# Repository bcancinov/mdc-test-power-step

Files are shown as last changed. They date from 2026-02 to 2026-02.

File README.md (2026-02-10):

# mdc-test-power-step
Modular Detector Controller Test Power Step Board

## Overview
This board generates controlled load steps at multiple bias rails to evaluate DC/DC module stability, settling, and control-loop bandwidth under different load conditions. It is intended to be used alongside the `mdc-power-*` DC/DC module boards.

## Objective
- Test stability and transient response across different bias rails.
- Measure settling time and bandwidth under programmable load conditions.

## System Context
- DC/DC generation is provided by the `mdc-power-*` boards.
- This board provides load-step capability and measurement access for those rails.
- Board input: 12V.

## Board Stackup
- 4-layer PCB

## Board Dimensions
- 136.4 mm x 105.35 mm

## CAD
- Designed using KiCad 9.

## Key Functions
- Programmable load steps using MOSFET-switched resistor banks.
- Multiple selectable load levels per rail.
- Local support rails and timing (LDO + oscillator) for step control.
- External 3.3V step input for injecting step signals on both positive and negative DUT outputs.
- 2 MHz oscillator to provide a sync reference for the DC-DC DUT.

## Images
Layout:
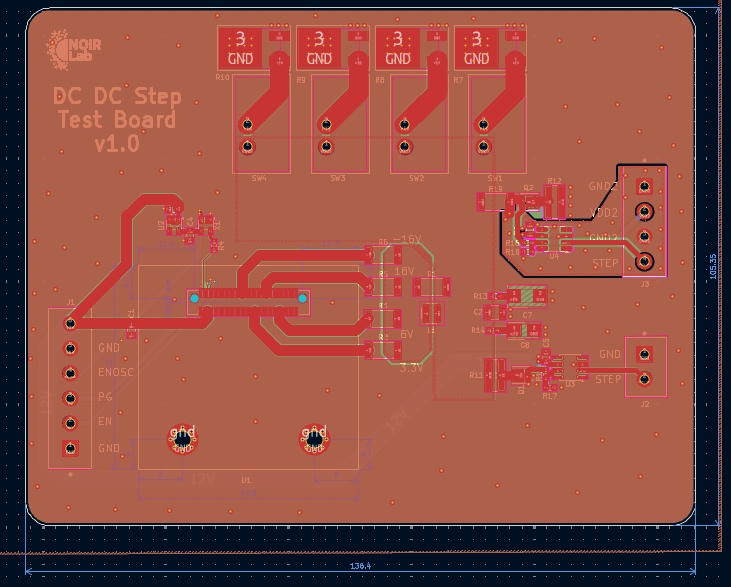
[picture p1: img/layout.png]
Layout


3D view:
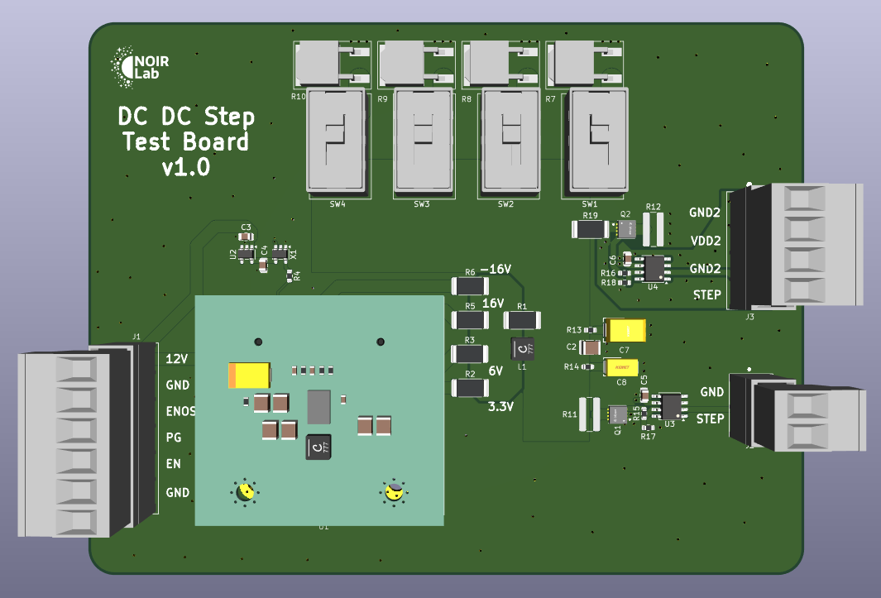
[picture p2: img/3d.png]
3D view


## Load Step Networks (from schematic)
High-power resistors (primary load steps):
- 3.3V: 2 ohm, 6 A, `PWR163S-25-2R00F`
- 6V: 8 ohm, 3 A, `PWR163S-25-8R00F`
- 16V: 120 ohm, 0.5 A, `PWR163S-25-1200F`

Alternate lower-power options (noted on schematic):
- 3.3V: 5.6 ohm, 0.6 A, `LTR100JZPF5R60`
- 6V: 20 ohm, 0.3 A, `LTR100JZPF20R0`
- 16V: 320 ohm, 0.05 A, `LTR100JZPF3300`

## Relevant ICs and Roles
- `U2: LP2980` LDO regulator for local low-power rail.
- `X1: SiT2024B` oscillator for step timing/control.
- `U3/U4: UCC27531D` gate drivers for MOSFET-switched loads.
- `Q1/Q2: ISZ015N04NM7V` power MOSFETs for load switching.

## Signals (from schematic)
- Control and status: `en`, `pg`, `sync`, `en_osc`, `step_pos`

## Files
- Schematic: `test_power_step.pdf`

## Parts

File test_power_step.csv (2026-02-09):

Reference | Qty | M | MPN | Description
C1,C3,C4,C5,C6 | 5 | Kemet | C0805C225K5RACAUTO | 2.2 ÂµF Â±10% 50V Ceramic Capacitor X7R 0805 (2012 Metric)
C7 | 1 | Kemet | T521X107M025ATE060 | 100 ÂµF Molded Tantalum Polymer Capacitor 25 V 2917 (7343 Metric) 60mOhm @ 100kHz
C8 | 1 | Kemet | T520L107M010ATE025 | 100 ÂµF Molded Tantalum Polymer Capacitor 10 V 2312 (6032 Metric) 25mOhm @ 100kHz
J1 | 1 | TE | 796636-6 | 6 Position Terminal Block Header, Male Pins, Shrouded (4 Side) 0.200" (5.08mm) Vertical Through Hole
J2 | 1 | TE | 796636-2 | 2 Position Terminal Block Header, Male Pins, Shrouded (4 Side) 0.200" (5.08mm) Vertical Through Hole
J3 | 1 | TE | 796636-4 | 4 Position Terminal Block Header, Male Pins, Shrouded (4 Side) 0.200" (5.08mm) Vertical Through Hole
J4 | 1 | TE | 796634-6 | 6 Position Terminal Block Header, Male Pins, Shrouded (4 Side) 0.200" (5.08mm) Vertical Through Hole
J5 | 1 | TE | 796634-2 | 2 Position Terminal Block Header, Male Pins, Shrouded (4 Side) 0.200" (5.08mm) Vertical Through Hole
J6 | 1 | TE | 796634-4 | 4 Position Terminal Block Header, Male Pins, Shrouded (4 Side) 0.200" (5.08mm) Vertical Through Hole
L1 | 1 | Coilcraft | XGL4020-102MEC | 1 ÂµH Shielded Molded Inductor 12 A 9mOhm Max 1616 (4040 Metric)
Q1,Q2 | 2 | Infineon | ISZ015N04NM7VATMA1 | N-Channel 40 V 32A (Ta), 177A (Tc) 3W (Ta), 94W (Tc) Surface Mount PG-TSDSON-8 FL
R1,R2,R3,R5,R6,R19 | 6 | Vishay | WSL251200000ZEA9 | 0 Ohms Jumper Chip Resistor 2512 (6332 Metric) Metal Element
R4 | 1 | Vishay | CRCW060333R0FKEA | 33 Ohms Â±1% 0.125W, 1/8W Chip Resistor 0603 (1608 Metric) Automotive AEC-Q200 Thick Film
R13,R14 | 2 | Vishay | RCWE0603R500FKEA | 500 mOhms Â±1% 0.2W, 1/5W Chip Resistor 0603 (1608 Metric) Automotive AEC-Q200, Current Sense, Moisture Resistant Thick Film
R15,R16 | 2 | Vishay | CRCW06034R70FKEAHP | 4.7 Ohms Â±1% 0.333W, 1/3W Chip Resistor 0603 (1608 Metric) Automotive AEC-Q200, Pulse Withstanding Thick Film
R17,R18 | 2 | Vishay | CRCW060310K0FKEAHP | 10 kOhms Â±1% 0.333W, 1/3W Chip Resistor 0603 (1608 Metric) Automotive AEC-Q200, Pulse Withstanding Thick Film
SW1,SW2,SW3,SW4 | 4 | C&K | L101121MS02Q | Single Pole Single Throw (SPST) switch
U2 | 1 | Texas | LP2980AIM5-3.3/NOPB | Linear Voltage Regulator IC Positive Fixed 1 Output 50mA SOT-23-5
U3,U4 | 2 | Texas | UCC27531D | Low-Side Gate Driver IC Non-Inverting 8-SOIC
X1 | 1 | SiTime | SIT2024BM-S1-33E-2.000000 | 2 MHz XO (Standard) LVCMOS, LVTTL Oscillator 3.3V Enable/Disable SC-74A, SOT-753
R11 | 1 | Rohm | LTR100JZPF5R60 | 5.6 Ohms ±1% 3W Chip Resistor Wide 2512 (6432 Metric), 1225 Automotive AEC-Q200, Pulse Withstanding Thick Film
R11 | 1 | Rohm | LTR100JZPF20R0 | 20 Ohms ±1% 3W Chip Resistor Wide 2512 (6432 Metric), 1225 Automotive AEC-Q200, Pulse Withstanding Thick Film
R11 | 2 | Rohm | LTR100JZPF3300 | 330 Ohms ±1% 3W Chip Resistor Wide 2512 (6432 Metric), 1225 Automotive AEC-Q200, Pulse Withstanding Thick Film
C2 | 1 | Murata | GCM32EC71H106KA03L | 10 µF ±10% 50V Ceramic Capacitor X7S 1210 (3225 Metric)
C2 | 2 | Taiyo | TMK325ABJ476MM-P | 47 µF ±20% 25V Ceramic Capacitor X5R 1210 (3225 Metric)
R7,R8,R9,R10 | 4 | Bourns | PWR163S-25-2R00F | 2 Ohms ±1% 25W Chip Resistor Non-Standard DPAK Automotive AEC-Q200, Current Sense, Pulse Withstanding Thick Film
R7,R8,R9,R10 | 4 | Bourns | PWR163S-25-8R00F | 8 Ohms ±1% 25W Chip Resistor Non-Standard DPAK Automotive AEC-Q200, Current Sense, Pulse Withstanding Thick Film
R7,R8,R9,R10 | 8 | Bourns | PWR163S-25-1200F | 120 Ohms ±1% 25W Chip Resistor Non-Standard DPAK Automotive AEC-Q200, Current Sense, Pulse Withstanding Thick Film

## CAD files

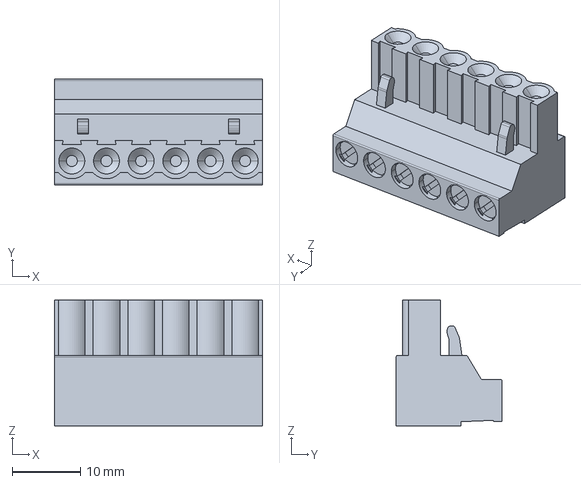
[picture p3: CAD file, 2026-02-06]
step/c-796634-6-r1-3d.stp
30.5 x 15.5 x 18.4 mm

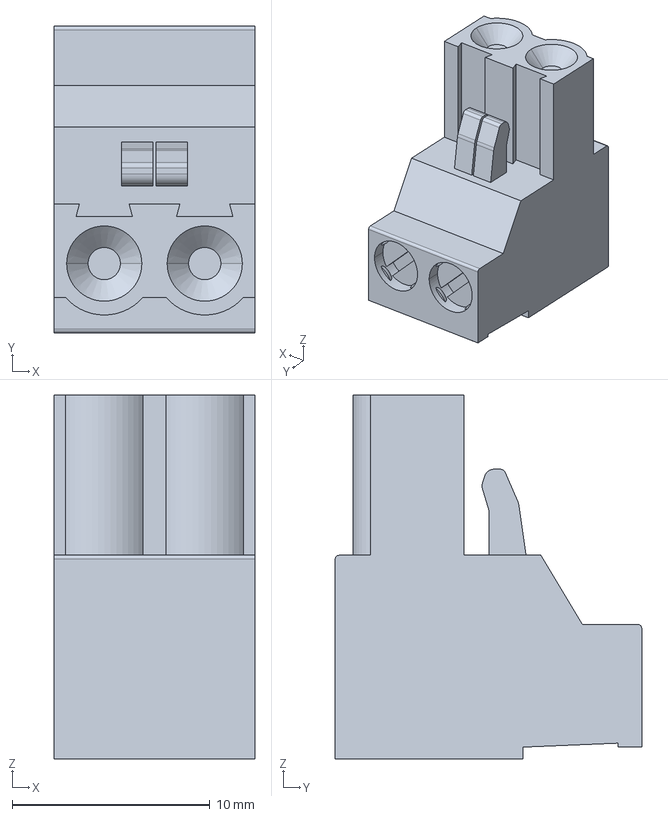
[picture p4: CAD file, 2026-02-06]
step/c-796634-2-r1-3d.stp
10.2 x 15.5 x 18.4 mm

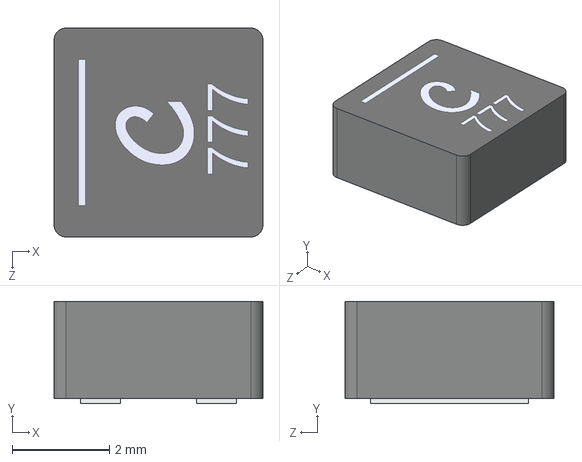
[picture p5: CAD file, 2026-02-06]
step/Coilcraft-XGL4020.step
4.30 x 2.10 x 4.30 mm

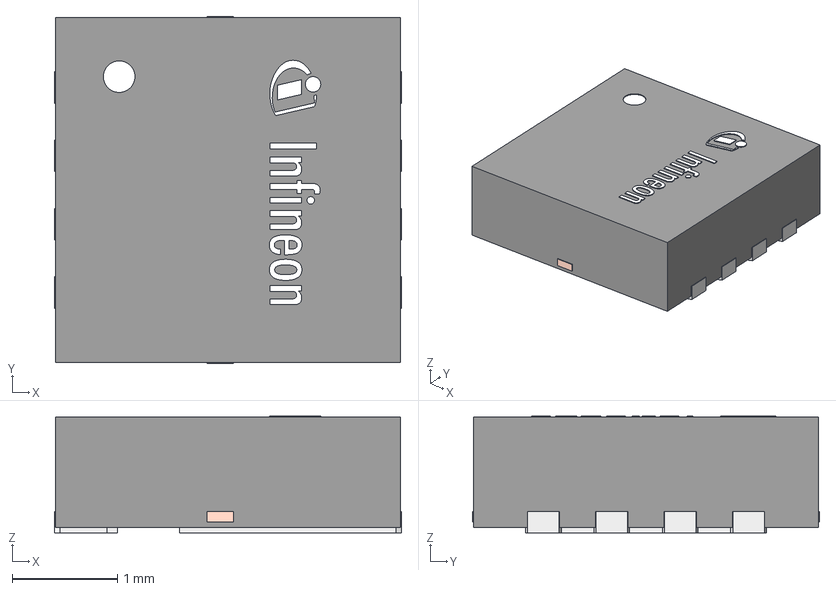
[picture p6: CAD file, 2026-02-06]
step/infineon-pg-tsdson-8-40-3d-stp-package-en.stp
3.30 x 3.30 x 1.11 mm

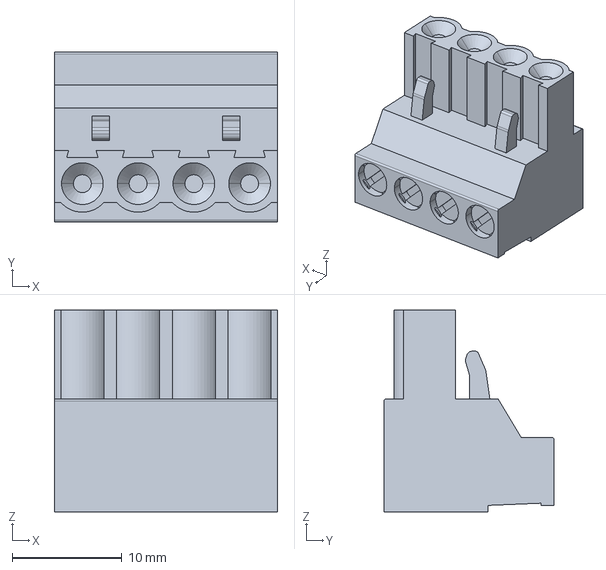
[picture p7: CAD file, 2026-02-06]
step/c-796634-4-r1-3d.stp
20.3 x 15.5 x 18.4 mm

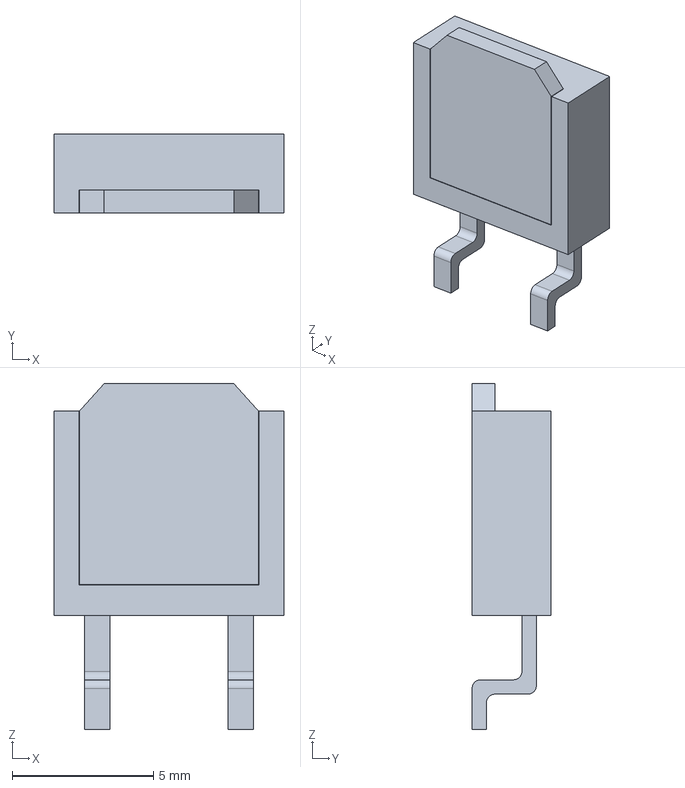
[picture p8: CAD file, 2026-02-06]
step/pwr163.stp
8.13 x 2.79 x 12.2 mm

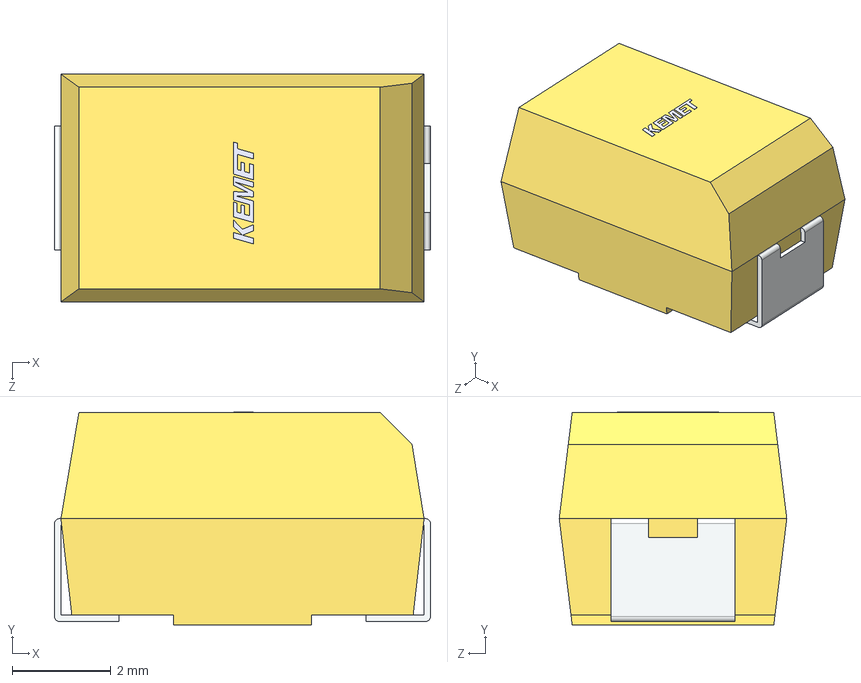
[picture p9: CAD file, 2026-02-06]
step/T521X.step
7.60 x 4.30 x 4.60 mm

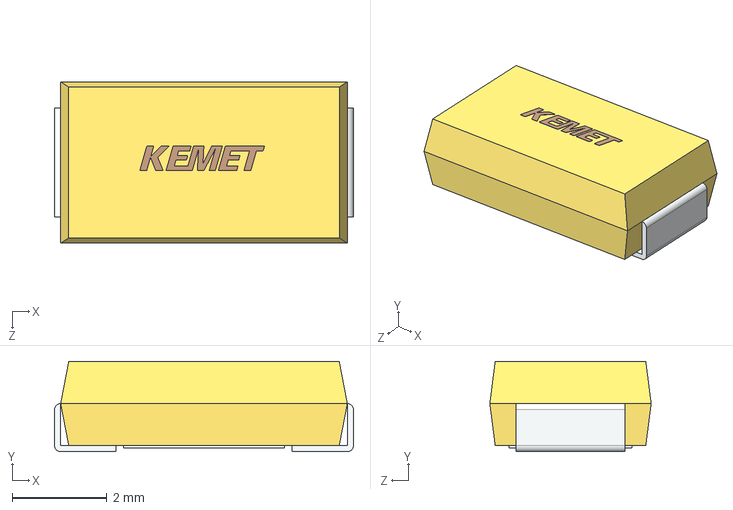
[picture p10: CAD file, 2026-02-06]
step/T52xL.step
6.30 x 1.91 x 3.40 mm

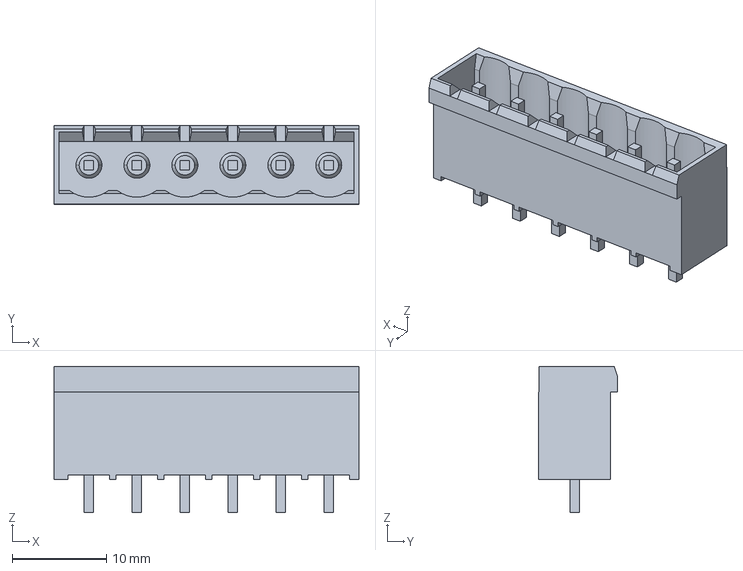
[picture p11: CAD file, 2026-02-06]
step/796636-6.stp
32.3 x 8.35 x 15.5 mm

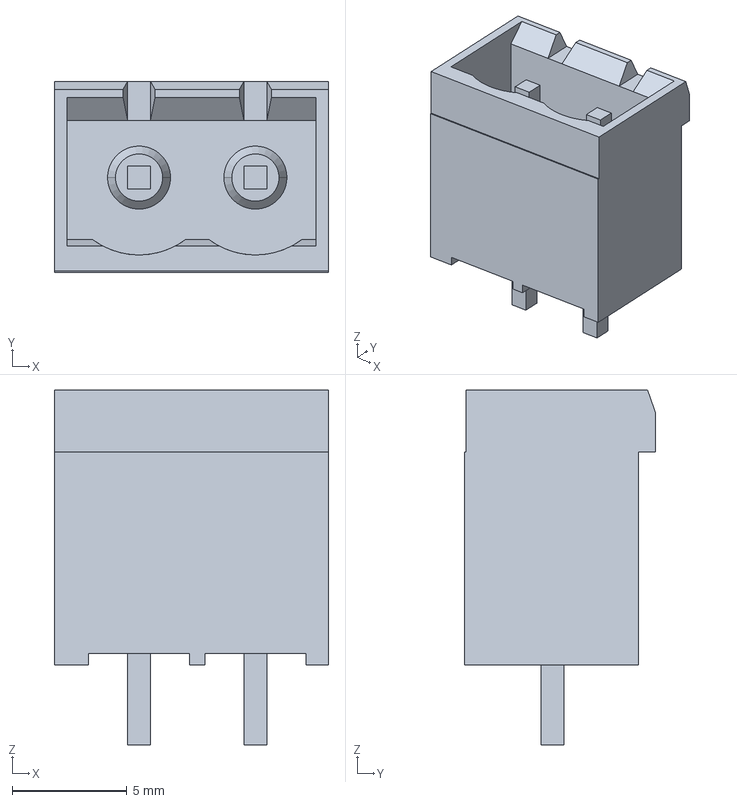
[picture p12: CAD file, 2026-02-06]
step/796636-2.STEP
12.0 x 8.35 x 15.5 mm

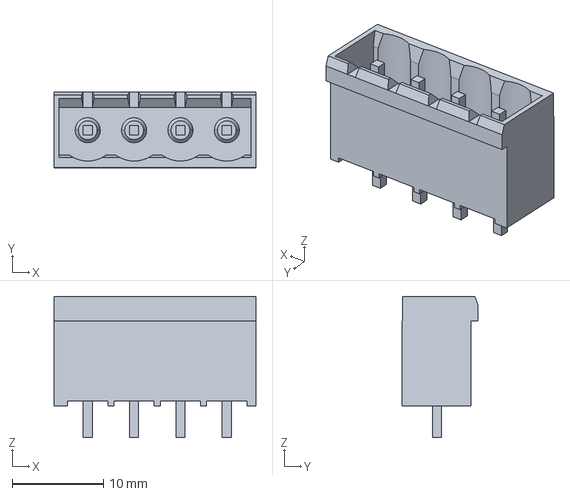
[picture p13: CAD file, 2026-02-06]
step/796636-4.stp
22.1 x 8.35 x 15.5 mm

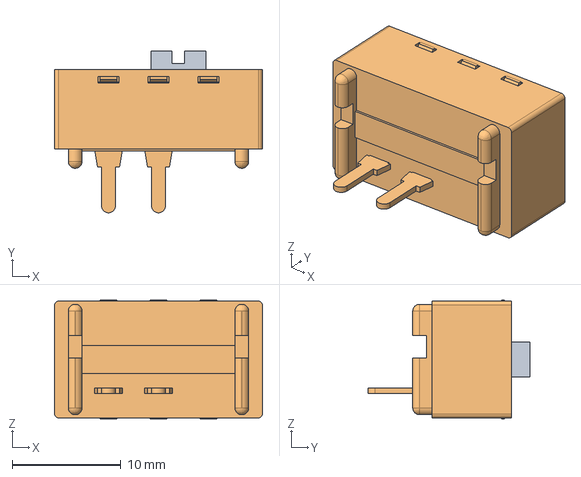
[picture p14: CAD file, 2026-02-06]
step/L101121MS02Q.stp
19.1 x 14.9 x 10.9 mm

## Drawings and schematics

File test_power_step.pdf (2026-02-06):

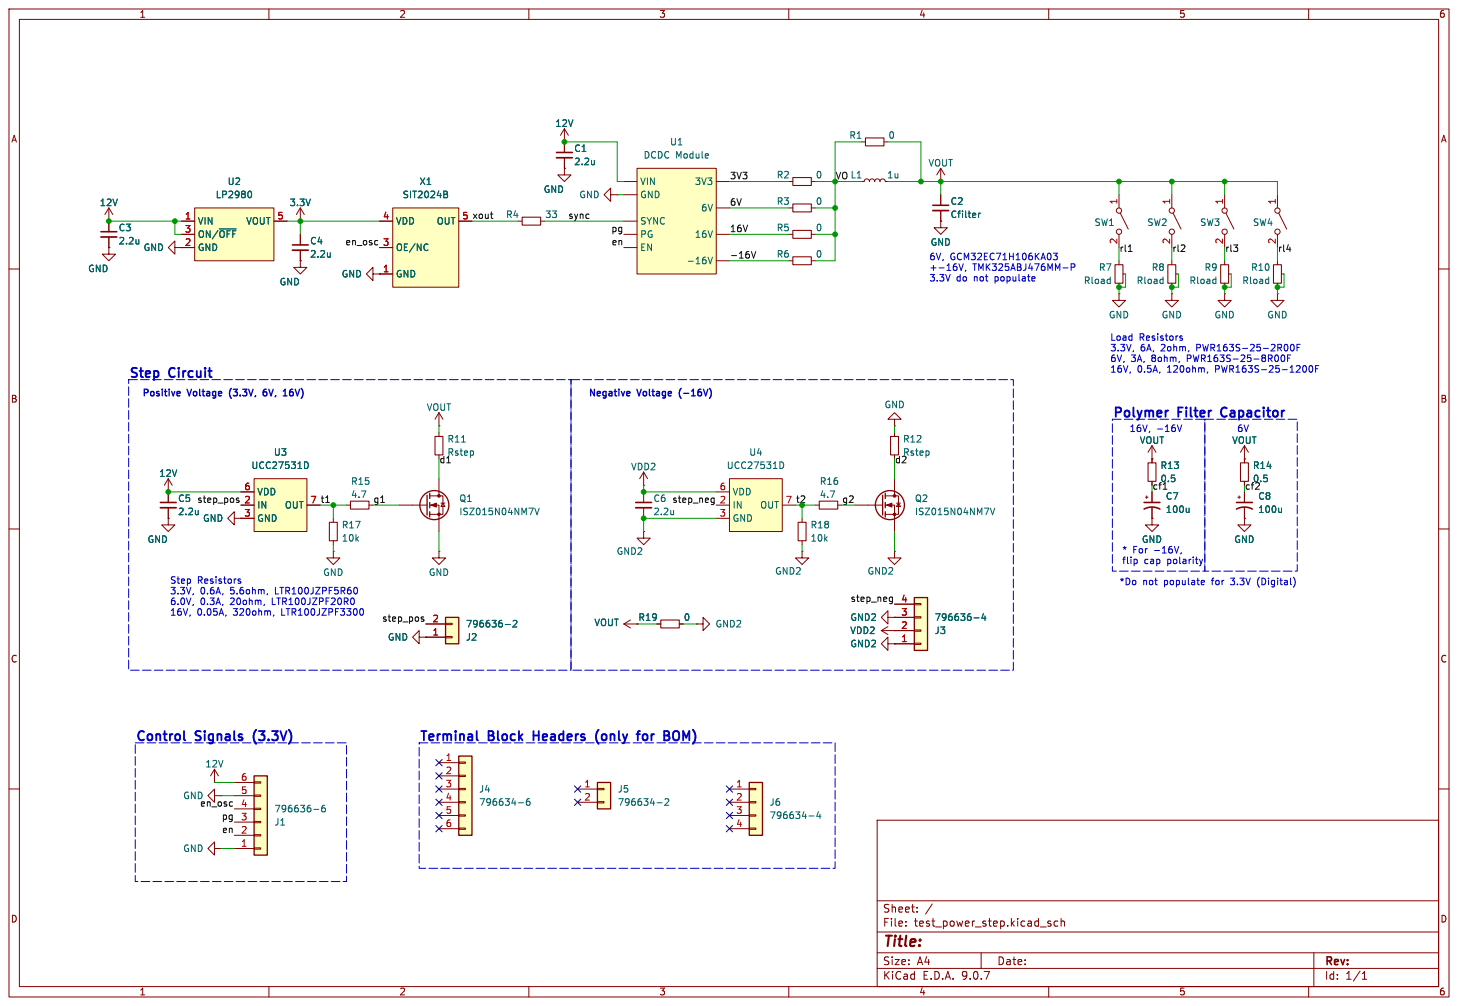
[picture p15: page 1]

3.3V do not populate Positive Voltage (3.3V, 6V, 16V)

Id: 1/1 Title: File: test_power_step.kicad_sch Sheet: /

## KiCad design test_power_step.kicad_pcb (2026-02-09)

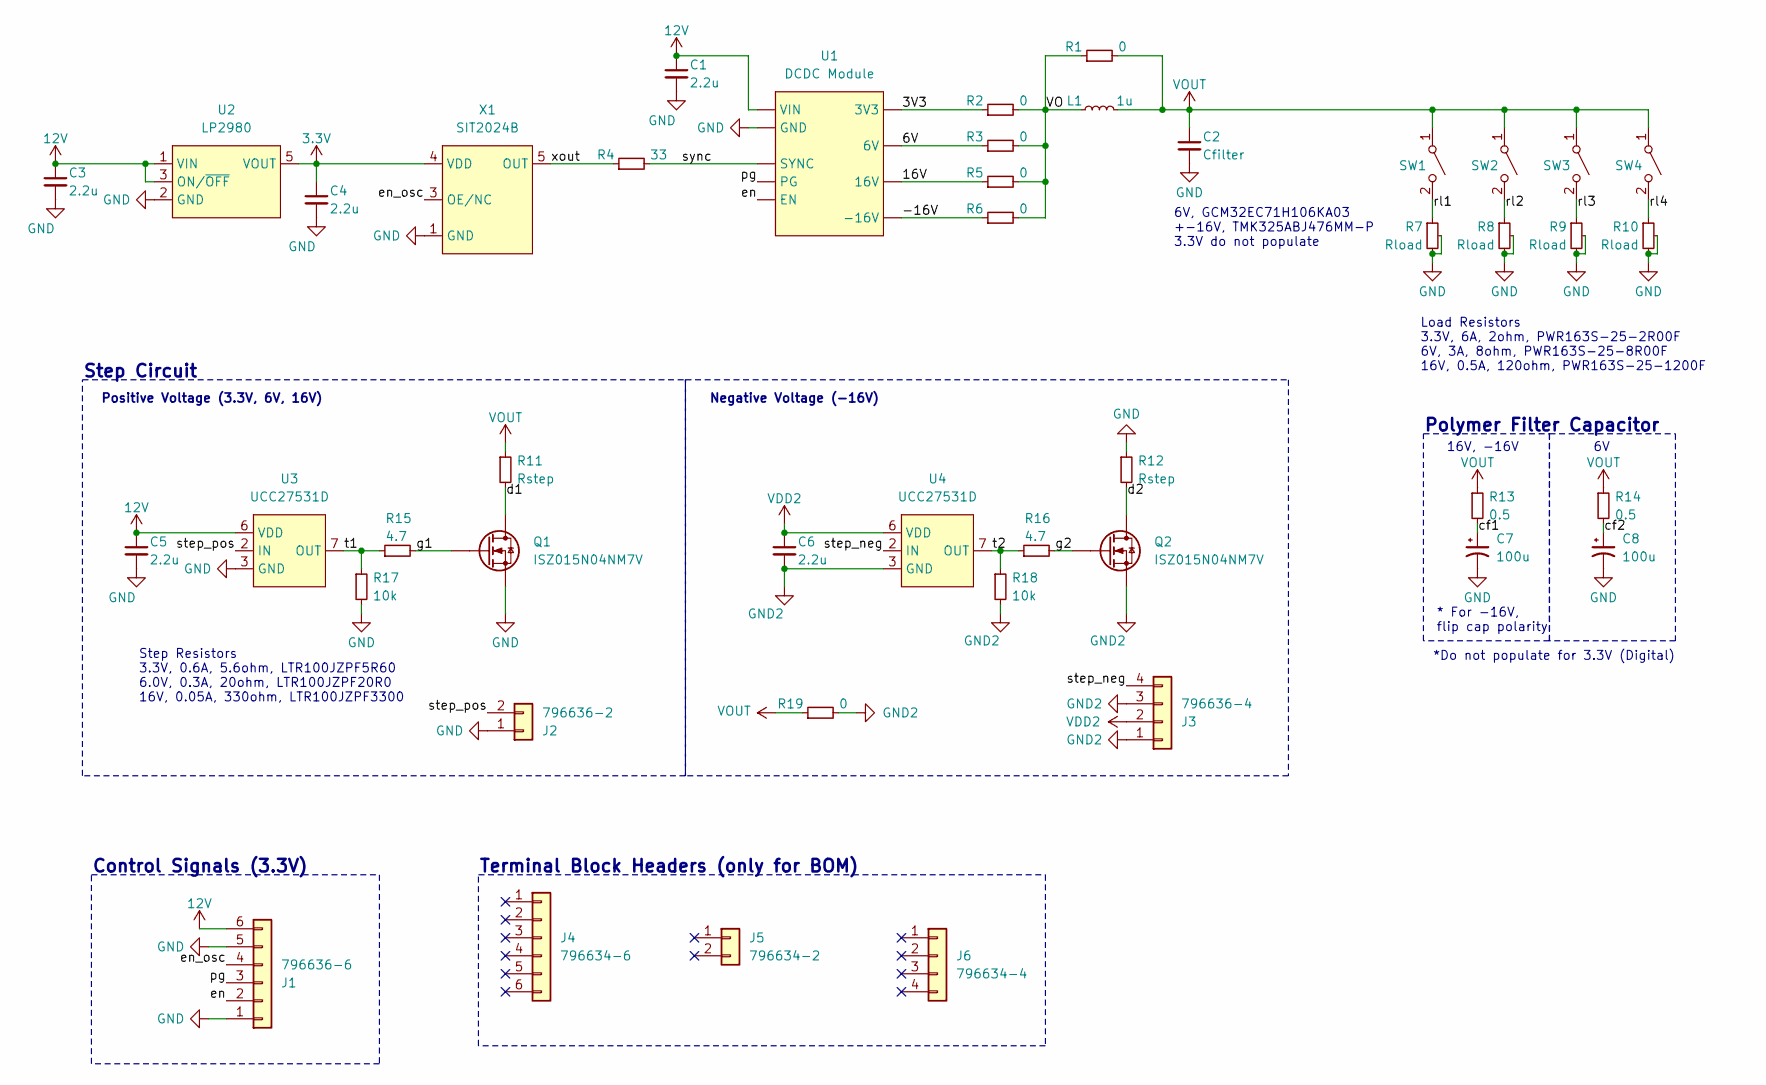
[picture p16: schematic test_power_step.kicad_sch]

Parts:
C1, C3, C4, C5, C6: 2.2u; C_0805_2012Metric; MPN C0805C225K5RACAUTO
C2: Cfilter; C_1210_3225Metric
C7: 100u; T521X; MPN T521X107M025ATE060
C8: 100u; T52xL; MPN T520L107M010ATE025
J1: 796636-6; CON6_P5MM_VER_TERM-BLK_TYC; MPN 796636-6
J2: 796636-2; CON2_P5MM_VER_TERM-BLK_TYC; MPN 796636-2
J3: 796636-4; CON4_P5MM_VER_TERM-BLK_TYC; MPN 796636-4
J4: 796634-6; CON6_P5MM_VER_TERM-BLK_TYC; MPN 796634-6
J5: 796634-2; CON2_P5MM_VER_TERM-BLK_TYC; MPN 796634-2
J6: 796634-4; CON4_P5MM_VER_TERM-BLK_TYC; MPN 796634-4
L1: 1u; XGL4020; MPN XGL4020-102MEC
Q1, Q2: ISZ015N04NM7V; TSDSON-8-40; MPN ISZ015N04NM7VATMA1
R1, R2, R3, R5, R6, R19: 0; R_2512_6332Metric; MPN WSL251200000ZEA9
R4: 33; R_0603_1608Metric; MPN CRCW060333R0FKEA
R7, R8, R9, R10: Rload; PWR163
R11, R12: Rstep; R_1225_3264Metric
R13, R14: 0.5; R_0603_1608Metric; MPN RCWE0603R500FKEA
R15, R16: 4.7; R_0603_1608Metric; MPN CRCW06034R70FKEAHP
R17, R18: 10k; R_0603_1608Metric; MPN CRCW060310K0FKEAHP
SW1, SW2, SW3, SW4: SW_SPST; L101; MPN L101121MS02Q
U1: DCDC Module; DCDC_module
U2: LP2980; SOT-23-5; MPN LP2980AIM5-3.3/NOPB
U3, U4: UCC27531D; SOIC-8_3.9x4.9mm_P1.27mm; MPN UCC27531D
X1: SIT2024B; SOT-23-5; MPN SIT2024BM-S1-33E-2.000000

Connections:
3.3V: C4.1, U2.5 (VOUT), X1.4 (VDD)
12V: C1.1, C3.1, C5.1, J1.6, U1.vin (VIN), U2.1 (VIN), U2.3 (ON/~OFF), U3.6 (VDD)
/3V3: R2.1, U1.3v3 (3V3)
/6V: R3.1, U1.6v (6V)
/16V: R5.1, U1.16v (16V)
/-16V: R6.1, U1.-16v (-16V)
/VO: L1.1, R1.1, R2.2, R3.2, R5.2, R6.2
/cf1: C7.1, R13.2
/cf2: C8.1, R14.2
/d1: Q1.D, R11.2
/d2: Q2.D, R12.2
/en: J1.2, U1.en (EN)
/en_osc: J1.4, X1.3 (OE/NC)
/g1: Q1.G, R15.2
/g2: Q2.G, R16.2
/pg: J1.3, U1.pg (PG)
/rl1: R7.1, SW1.2 (B)
/rl2: R8.1, SW2.2 (B)
/rl3: R9.1, SW3.2 (B)
/rl4: R10.1, SW4.2 (B)
/step_neg: J3.4, U4.2 (IN)
/step_pos: J2.2, U3.2 (IN)
/sync: R4.2, U1.sync (SYNC)
/t1: R15.1, R17.1, U3.7 (OUT)
/t2: R16.1, R18.1, U4.7 (OUT)
/xout: R4.1, X1.5 (OUT)
GND: C1.2, C2.2, C3.2, C4.2, C5.2, C7.2, C8.2, J1.1, J1.5, J2.1, Q1.S, R7.2, R7.3, R8.2, R8.3, R9.2, R9.3, R10.2, R10.3, R12.1, R17.2, U1.gnd (GND), U2.2 (GND), U3.3 (GND), X1.1 (GND)
GND2: C6.2, J3.1, J3.3, Q2.S, R18.2, R19.2, U4.3 (GND)
VDD2: C6.1, J3.2, U4.6 (VDD)
VOUT: C2.1, L1.2, R1.2, R11.1, R13.1, R14.1, R19.1, SW1.1 (A), SW2.1 (A), SW3.1 (A), SW4.1 (A)

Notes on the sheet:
Load Resistors 3.3V, 6A, 2ohm, PWR163S-25-2R00F 6V, 3A, 8ohm, PWR163S-25-8R00F 16V, 0.5A, 120ohm, PWR163S-25-1200F
*Do not populate for 3.3V (Digital)
* For -16V, flip cap polarity
Control Signals (3.3V)
Positive Voltage (3.3V, 6V, 16V)
Negative Voltage (-16V)
Polymer Filter Capacitor
Terminal Block Headers (only for BOM)
Step Circuit
Step Resistors 3.3V, 0.6A, 5.6ohm, LTR100JZPF5R60 6.0V, 0.3A, 20ohm, LTR100JZPF20R0 16V, 0.05A, 330ohm, LTR100JZPF3300
16V, -16V
6V, GCM32EC71H106KA03 +-16V, TMK325ABJ476MM-P 3.3V do not populate

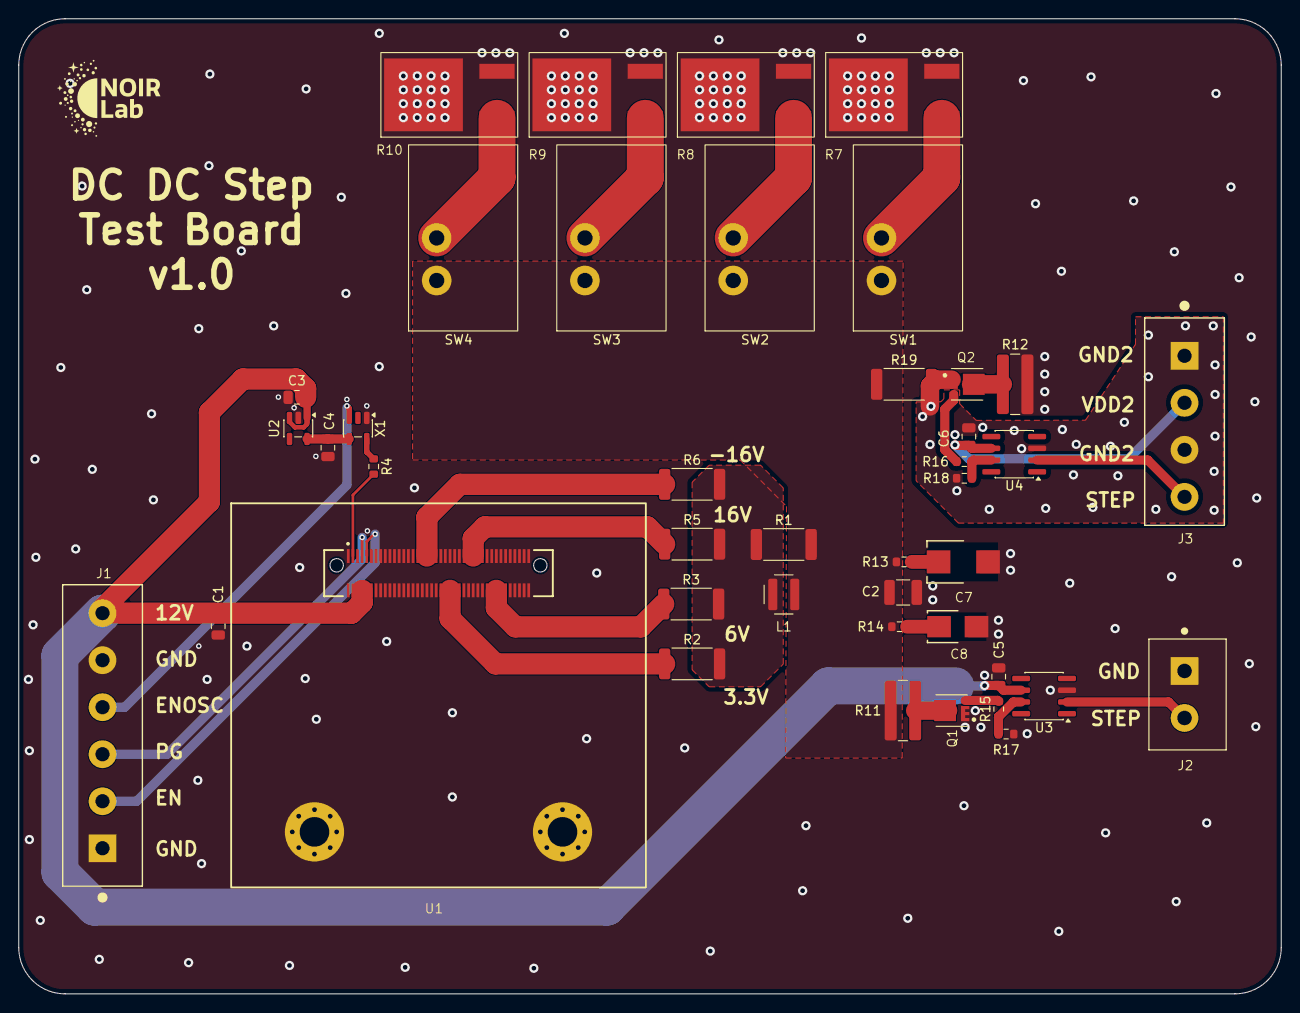
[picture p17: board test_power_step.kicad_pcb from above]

Board: 4 copper layers, 136.4 x 105.3 mm, 42 parts (0 on the bottom side), 30 nets.

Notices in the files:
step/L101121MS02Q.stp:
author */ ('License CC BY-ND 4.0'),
